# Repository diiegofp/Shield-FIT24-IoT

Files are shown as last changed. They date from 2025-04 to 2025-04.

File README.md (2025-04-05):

# Shield FIT24-IoT
Este dispositivo fue creado para el track de IoT en el Foro de Innovación Tecnológica (FIT), evento organizado en Universidad Galileo por el laboratorio de Investigación Tesla Lab. Además, fue diseñado y ensamblado en Guatemala. Su principal objetivo es mandar datos del sensor BME680 a través de la tecnología LoRa.

# ¿Qué podemos hacer?

Desplegar información por medio de un web server o dashboard a través de LoRa. Obtener mediciones de temperatura, humedad y presión atmosférica a través del sensor BME680. Además, cuenta con 3 Neopixeles, un Buzzer para emitir algún sonido o alerta y pin headers para conectar otro dispositivo por I2C.

# Pinout

### Buzzer
Nombre | PIN 
--- | --- 
IN | 10
VDD | 5V
VSS | GND

### NPX - WS2812B
Nombre | PIN 
--- | --- 
DIN | 11
VDD | 5V
VSS | GND

### Sensor de temperatura, humedad, presión y gas  - Comunicación I2C 
BME680 | RAK4260
--- | ---
SDI 3 | SDA PA16
SCK 4 |  SCL PA17

# Licencia

Hardware License: CERN Open Hardware License Version 2.0

Software License: GNU General Public License Version 3.0

Documentation License: CC BY 4.0 International



# Contacto

Autor: Diego Iboy (diego.iboy@galileo.edu)

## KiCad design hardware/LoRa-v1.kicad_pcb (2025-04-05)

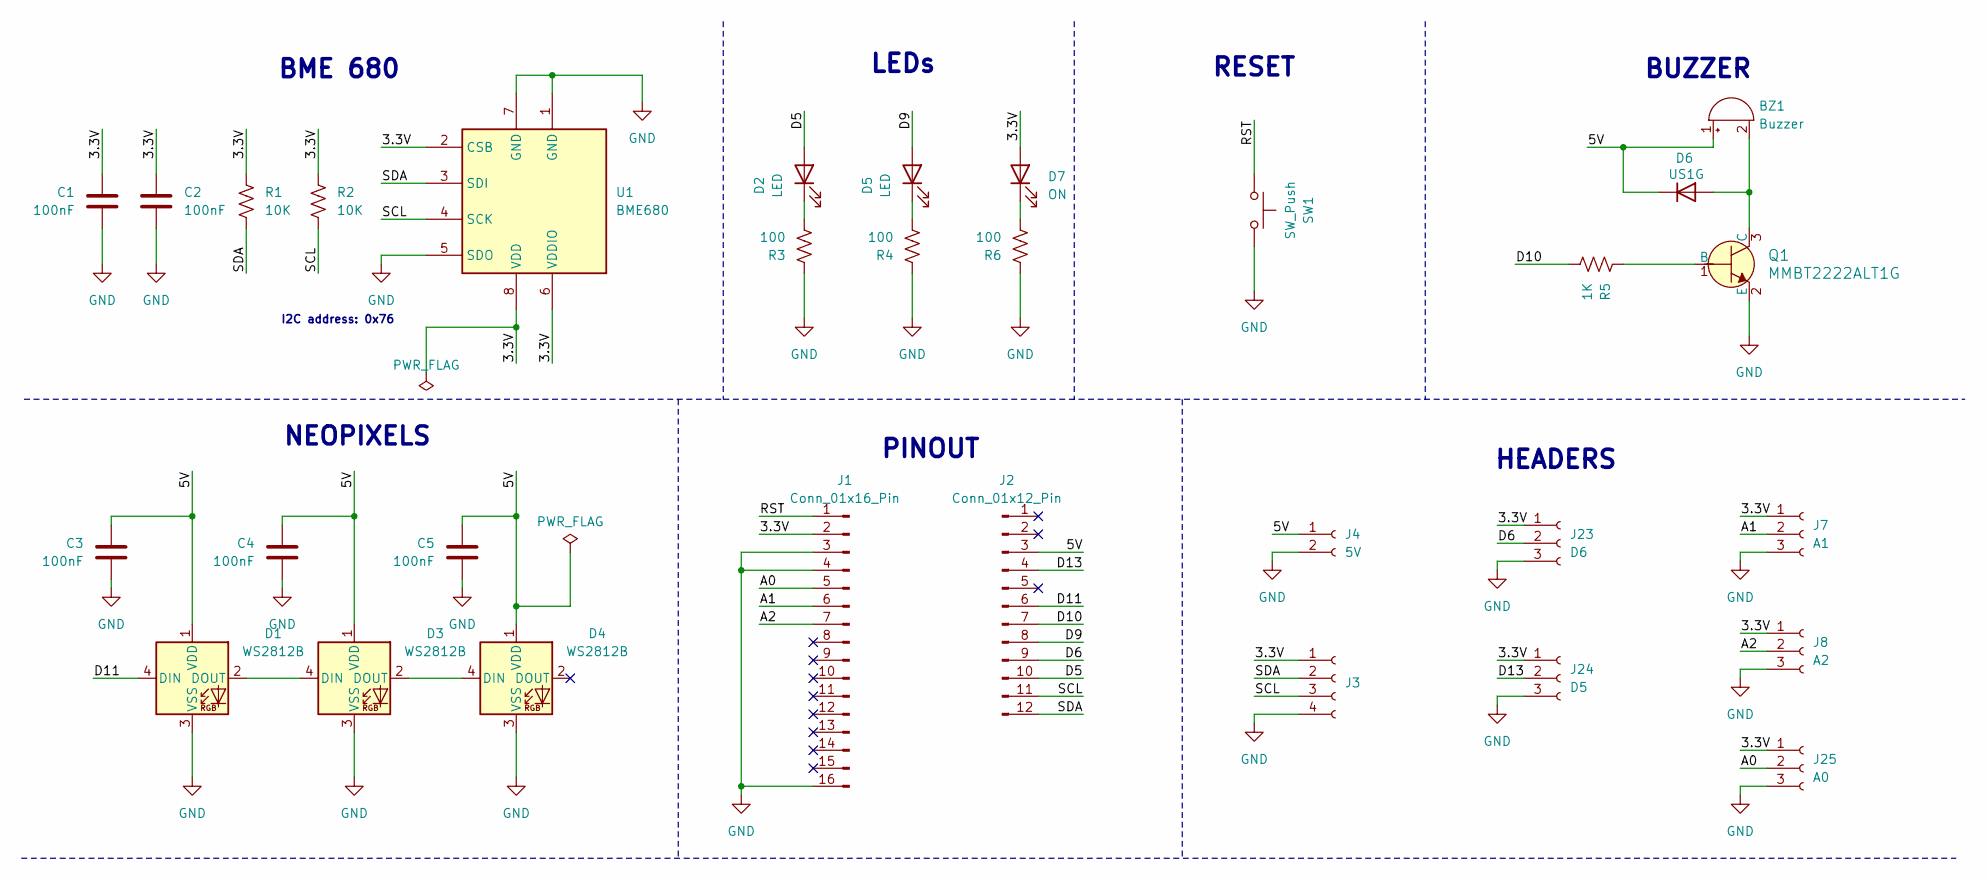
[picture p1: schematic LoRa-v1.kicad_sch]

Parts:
BZ1: Buzzer; Buzzer_TDK_PS1240P02BT_D12.2mm_H6.5mm
C1, C2, C3, C4, C5: 100nF; C_0805_2012Metric
D1, D3, D4: WS2812B; LED_WS2812B_PLCC4_5.0x5.0mm_P3.2mm
D2, D5: LED; LED_1206_3216Metric
D6: US1G; D_SMA
D7: ON; LED_1206_3216Metric
J1: Conn_01x16_Pin; PinSocket_1x16_P2.54mm_Vertical
J2: Conn_01x12_Pin; PinSocket_1x12_P2.54mm_Vertical
J3: PinHeader_1x04_P2.54mm_Vertical
J4: 5V; PinHeader_1x02_P2.54mm_Vertical
J7: A1; PinHeader_1x03_P2.54mm_Vertical
J8: A2; PinHeader_1x03_P2.54mm_Vertical
J23: D6; PinHeader_1x03_P2.54mm_Vertical
J24: D5; PinHeader_1x03_P2.54mm_Vertical
J25: A0; PinHeader_1x03_P2.54mm_Vertical
Q1: MMBT2222ALT1G; SOT-23-3; MPN MMBT2222ALT1G; Digi-Key_PN MMBT2222ALT1GOSCT-ND
R1, R2: 10K; R_0805_2012Metric
R3, R4, R6: 100; R_0805_2012Metric
R5: 1K; R_0805_2012Metric
SW1: SW_Push; SW_SPST_B3U-3100P-B
U1: BME680; Bosch_LGA-8_3x3mm_P0.8mm_ClockwisePinNumbering

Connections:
/3.3V: C1.1, C2.1, D7.2 (A), J1.2, J3.1, J7.1, J8.1, J23.1, J24.1, J25.1, R1.1, R2.1, U1.2 (CSB), U1.6 (VDDIO), U1.8 (VDD)
/5V: BZ1.1 (+), C3.1, C4.1, C5.1, D1.1 (VDD), D3.1 (VDD), D4.1 (VDD), D6.1 (K), J2.3, J4.1
/A0: J1.5, J25.2
/A1: J1.6, J7.2
/A2: J1.7, J8.2
/D5: D2.2 (A), J2.10
/D6: J2.9, J23.2
/D9: D5.2 (A), J2.8
/D10: J2.7, R5.1
/D11: D1.4 (DIN), J2.6
/D13: J2.4, J24.2
/RST: J1.1, SW1.2
/SCL: J2.11, J3.3, R2.2, U1.4 (SCK)
/SDA: J2.12, J3.2, R1.2, U1.3 (SDI)
GND: C1.2, C2.2, C3.2, C4.2, C5.2, D1.3 (VSS), D3.3 (VSS), D4.3 (VSS), J1.3, J1.4, J1.16, J3.4, J4.2, J7.3, J8.3, J23.3, J24.3, J25.3, Q1.2 (E), R3.2, R4.2, R6.2, SW1.1, U1.1 (GND), U1.5 (SDO), U1.7 (GND)
unnamed: BZ1.2 (-), D6.2 (A), Q1.3 (C)
unnamed: D1.2 (DOUT), D3.4 (DIN)
unnamed: D2.1 (K), R3.1
unnamed: D3.2 (DOUT), D4.4 (DIN)
unnamed: D5.1 (K), R4.1
unnamed: D7.1 (K), R6.1
unnamed: Q1.1 (B), R5.2

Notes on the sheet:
I2C address: 0x76
NEOPIXELS
HEADERS
RESET
PINOUT
BME 680
LEDs
BUZZER

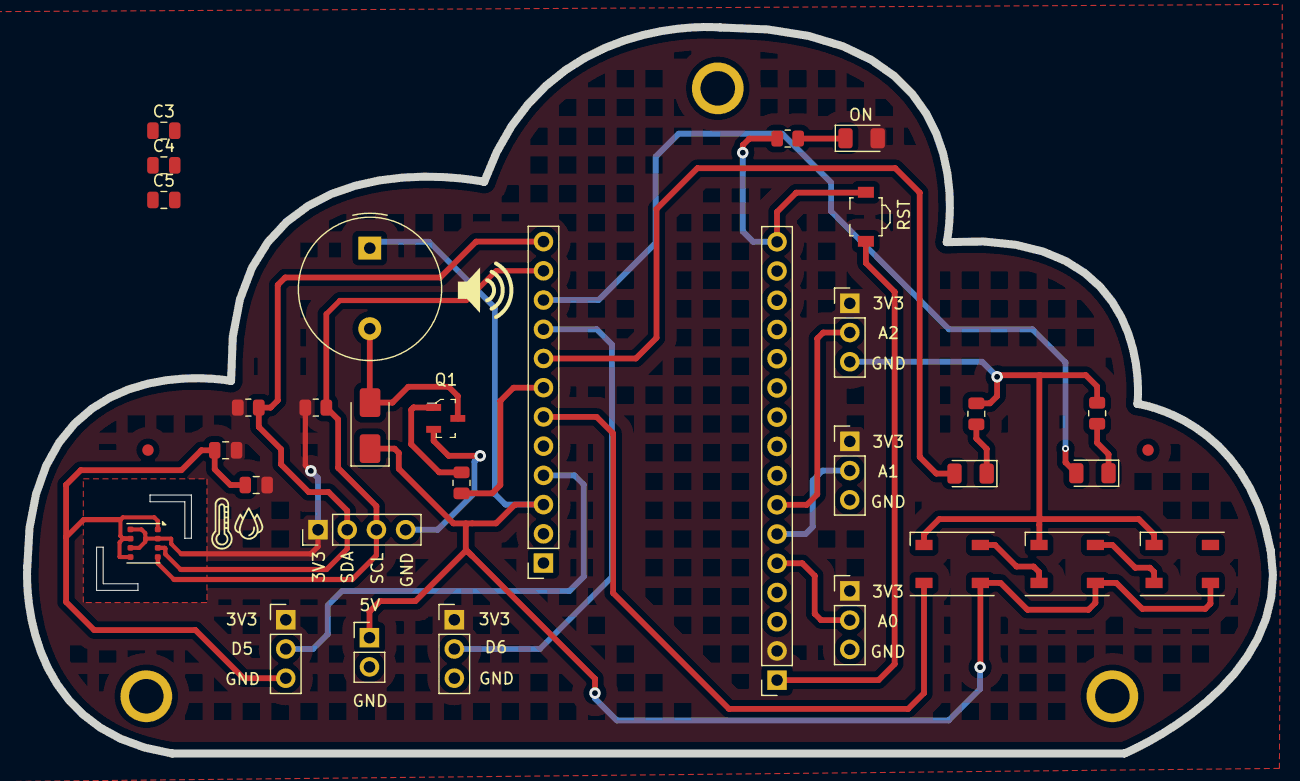
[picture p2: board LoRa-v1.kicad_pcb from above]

Board: 2 copper layers, 108.3 x 63.1 mm, 31 parts (0 on the bottom side), 22 nets.
